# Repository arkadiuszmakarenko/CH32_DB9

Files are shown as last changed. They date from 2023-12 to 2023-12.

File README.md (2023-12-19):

Work in progress.

USB HID to DB9 Adapter
It has been desigend for dual use, but primarily for MSX computers.

Current support:
- MSX Gamepad

2023-12-19 16_24_46-JLCPCB PCBA Viewer

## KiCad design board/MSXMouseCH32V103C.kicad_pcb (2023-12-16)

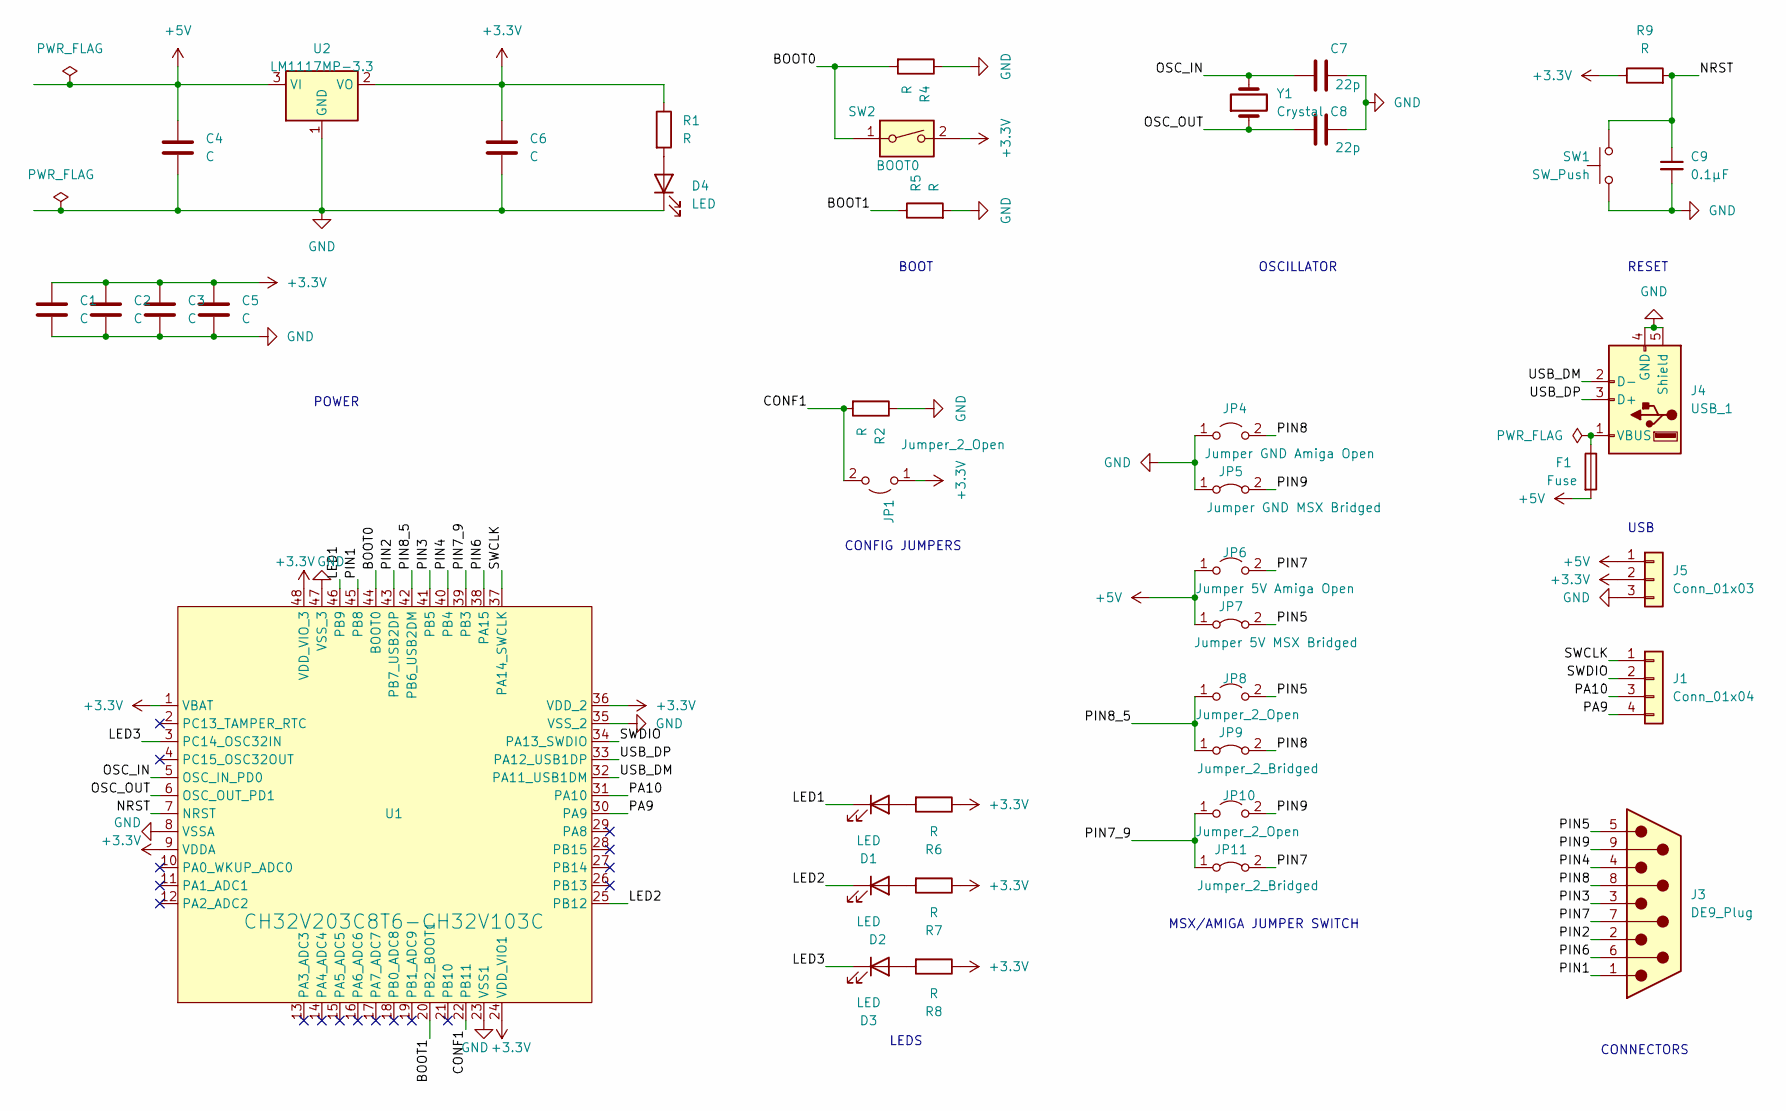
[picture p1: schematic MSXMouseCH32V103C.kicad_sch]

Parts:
C1, C2, C3, C4, C5, C6: C; C_0805_2012Metric_Pad1.18x1.45mm_HandSolder
C7, C8: 22p; C_0805_2012Metric_Pad1.18x1.45mm_HandSolder
C9: 0.1μF; C_0603_1608Metric; LCSC C14663
D1, D2, D3, D4: LED; LED_0805_2012Metric_Pad1.15x1.40mm_HandSolder
F1: Fuse; Fuse_1206_3216Metric_Pad1.42x1.75mm_HandSolder
J1: Conn_01x04; PinHeader_1x04_P2.54mm_Vertical
J3: DE9_Plug; DSUB-9_Female_EdgeMount_P2.77mm
J4: USB_1; USB_A_CONNFLY_DS1095-WNR0
J5: Conn_01x03; PinHeader_1x03_P2.54mm_Vertical
JP1, JP8, JP10: Jumper_2_Open; SolderJumper-2_P1.3mm_Open_RoundedPad1.0x1.5mm
JP4: Jumper GND Amiga Open; SolderJumper-2_P1.3mm_Open_RoundedPad1.0x1.5mm
JP5: Jumper GND MSX Bridged; SolderJumper-2_P1.3mm_Bridged_RoundedPad1.0x1.5mm
JP6: Jumper 5V Amiga Open; SolderJumper-2_P1.3mm_Open_RoundedPad1.0x1.5mm
JP7: Jumper 5V MSX Bridged; SolderJumper-2_P1.3mm_Bridged_RoundedPad1.0x1.5mm
JP9, JP11: Jumper_2_Bridged; SolderJumper-2_P1.3mm_Bridged_RoundedPad1.0x1.5mm
R1, R2, R4, R5, R6, R7, R8, R9: R; R_0805_2012Metric_Pad1.20x1.40mm_HandSolder
SW1: SW_Push; PinSocket_1x02_P2.54mm_Vertical; LCSC C2888884
SW2: BOOT0; PinHeader_1x02_P2.54mm_Vertical
U1: CH32V203C8T6-CH32V103C; CH32V203C8T6_LQFP-48_7x7mm_P0.5mm
U2: LM1117MP-3.3; SOT-223-3_TabPin2
Y1: Crystal; Crystal_HC49-U_Vertical

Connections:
+3.3V: C1.1, C2.1, C3.1, C5.1, C6.1, J5.2, JP1.1 (A), R1.1, R6.1, R7.1, R8.1, R9.1, SW2.2, U1.1 (VBAT), U1.9 (VDDA), U1.24 (VDD_VIO1), U1.36 (VDD_2), U1.48 (VDD_VIO_3), U2.2 (VO)
+5V: C4.1, F1.2, J5.1, JP6.1 (A), JP7.1 (A), U2.3 (VI)
/BOOT0: R4.2, SW2.1, U1.44 (BOOT0)
/BOOT1: R5.1, U1.20 (PB2_BOOT1)
/CONF1: JP1.2 (B), R2.2, U1.22 (PB11)
/LED1: D1.1 (K), U1.46 (PB9)
/LED2: D2.1 (K), U1.25 (PB12)
/LED3: D3.1 (K), U1.3 (PC14_OSC32IN)
/NRST: C9.1, R9.2, SW1.2, U1.7 (NRST)
/OSC_IN: C7.1, U1.5 (OSC_IN_PD0), Y1.2
/OSC_OUT: C8.1, U1.6 (OSC_OUT_PD1), Y1.1
/PA9: J1.4, U1.30 (PA9)
/PA10: J1.3, U1.31 (PA10)
/PIN1: J3.1, U1.45 (PB8)
/PIN2: J3.2, U1.43 (PB7_USB2DP)
/PIN3: J3.3, U1.41 (PB5)
/PIN4: J3.4, U1.40 (PB4)
/PIN5: J3.5, JP7.2 (B), JP8.2 (B)
/PIN6: J3.6, U1.38 (PA15)
/PIN7: J3.7, JP6.2 (B), JP11.2 (B)
/PIN7_9: JP10.1 (A), JP11.1 (A), U1.39 (PB3)
/PIN8: J3.8, JP4.2 (B), JP9.2 (B)
/PIN8_5: JP8.1 (A), JP9.1 (A), U1.42 (PB6_USB2DM)
/PIN9: J3.9, JP5.2 (B), JP10.2 (B)
/SWCLK: J1.1, U1.37 (PA14_SWCLK)
/SWDIO: J1.2, U1.34 (PA13_SWDIO)
/USB_DM: J4.2 (D-), U1.32 (PA11_USB1DM)
/USB_DP: J4.3 (D+), U1.33 (PA12_USB1DP)
GND: C1.2, C2.2, C3.2, C4.2, C5.2, C6.2, C7.2, C8.2, C9.2, D4.1 (K), J4.4 (GND), J4.5 (Shield), J5.3, JP4.1 (A), JP5.1 (A), R2.1, R4.1, R5.2, SW1.1, U1.8 (VSSA), U1.23 (VSS1), U1.35 (VSS_2), U1.47 (VSS_3), U2.1 (GND)
unnamed: D1.2 (A), R6.2
unnamed: D2.2 (A), R7.2
unnamed: D3.2 (A), R8.2
unnamed: D4.2 (A), R1.2
unnamed: F1.1, J4.1 (VBUS)

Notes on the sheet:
CONNECTORS
CONFIG JUMPERS
OSCILLATOR
LEDS
MSX/AMIGA JUMPER SWITCH
USB
BOOT
POWER
RESET

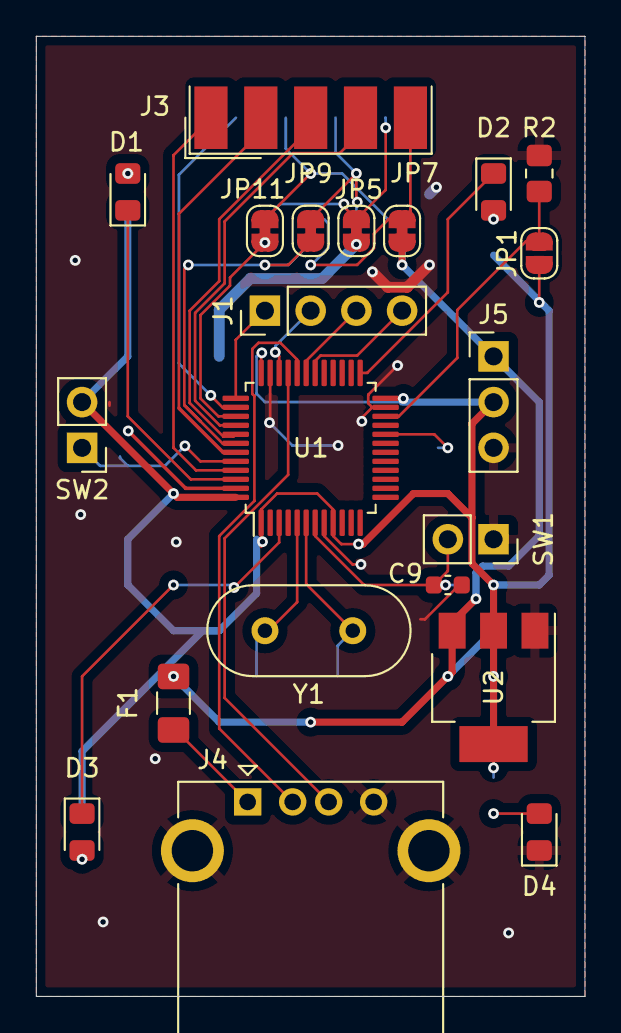
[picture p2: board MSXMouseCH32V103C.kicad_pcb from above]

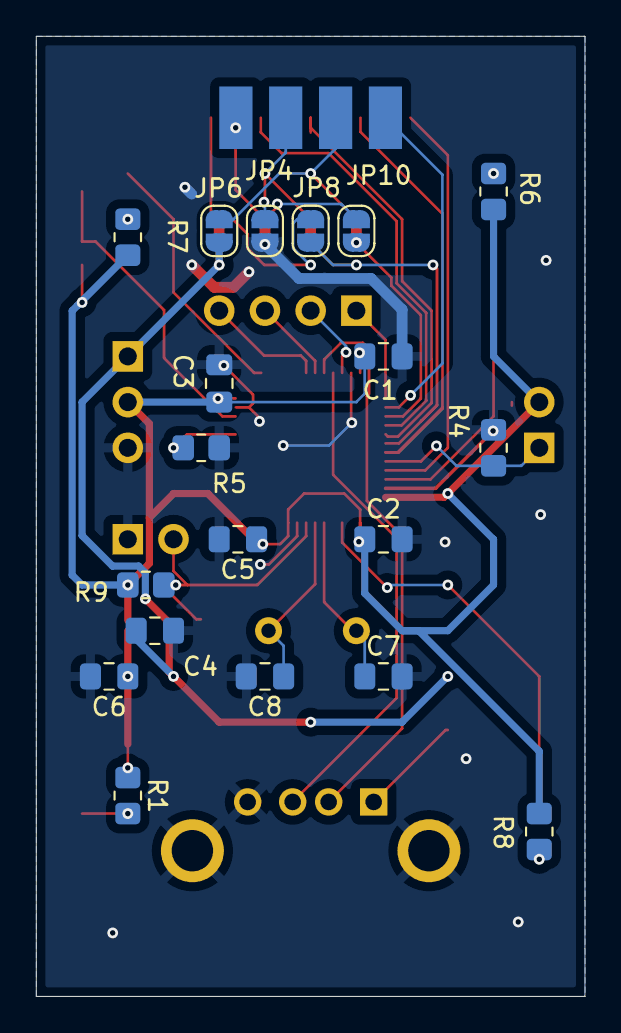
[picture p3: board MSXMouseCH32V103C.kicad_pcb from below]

Board: 2 copper layers, 30.5 x 53.3 mm, 40 parts (19 on the bottom side), 34 nets.

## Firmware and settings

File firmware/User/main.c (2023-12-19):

/********************************** (C) COPYRIGHT *******************************
 * File Name          : main.c
 * Author             : WCH
 * Version            : V1.0.0
 * Date               : 2020/04/30
 * Description        : Main program body.
 *********************************************************************************
 * Copyright (c) 2021 Nanjing Qinheng Microelectronics Co., Ltd.
 * Attention: This software (modified or not) and binary are used for 
 * microcontroller manufactured by Nanjing Qinheng Microelectronics.
 *******************************************************************************/

/*
 *@Note
 *USART Print debugging routine:
 *USART1_Tx(PA9).
 *This example demonstrates using USART1(PA9) as a print debug port output.
 *
 */

#include "debug.h"

/*******************************************************************************/
/* Header File */
#include <USB_Host/usb_gamepad.h>
#include <USB_Host/usb_mouse.h>
#include <USB_Host/usb_keyboard.h>
#include "USB_Host/usb_host_config.h"
#include "utils.h"
#include "tim.h"
#include "mouseAmiga.h"
#include "mouseMSX.h"
#include "gpio.h"
#include "gamepadAmiga.h"
#include "gamepadMSX.h"

/*********************************************************************
 * @fn      main
 *
 * @brief   Main program.
 *
 * @return  none
 */



int main(void)
{
    uint8_t CONFIG1 = 0;

    NVIC_PriorityGroupConfig(NVIC_PriorityGroup_2);
    SystemCoreClockUpdate();
    Delay_Init();
    USART_Printf_Init(115200);
    DUG_PRINTF( "ChipID:%08x\r\n", DBGMCU_GetCHIPID() );
    DUG_PRINTF( "SystemClk:%d\r\n", SystemCoreClock );
    DUG_PRINTF( "USBHD HOST KM Test\r\n" );

    /* Initialize timer for obtaining keyboard and mouse data at regular intervals */
    TIM3_Init( 9, SystemCoreClock / 10000 - 1 );
    DUG_PRINTF( "TIM3 Init OK!\r\n" );

    /* Configure USB clock and initialize USB host */
#if DEF_USBHD_PORT_EN
    USBHD_RCC_Init( );
    USBHD_Host_Init( ENABLE , PWR_VDD_SupplyVoltage());
    memset( &RootHubDev.bStatus, 0, sizeof( ROOT_HUB_DEVICE ) );
    memset( &HostCtl[ DEF_USBHD_PORT_INDEX * DEF_ONE_USB_SUP_DEV_TOTAL ].InterfaceNum, 0, DEF_ONE_USB_SUP_DEV_TOTAL * sizeof( HOST_CTL ) );
#endif
	GPIO_Config();
	 //Read value of CONFIG1
	CONFIG1 = GPIO_ReadInputDataBit(CONFIG1_GPIO_Port, CONFIG1_Pin);


	DUG_PRINTF( "CONFIG1:%d\r\n", CONFIG1);

	while (1) {
		USBH_MainDeal();

		//Handle HID Device
		if (RootHubDev.bType == USB_DEV_CLASS_HID) {

			for (int itf = 0; itf < DEF_INTERFACE_NUM_MAX; itf++) {
				//Handle mouse
				if (HostCtl[0].Interface[itf].HIDRptDesc.type
						== REPORT_TYPE_MOUSE) {
					HID_MOUSE_Info_TypeDef *mousemap = USBH_GetMouseInfo(
							&HostCtl[0].Interface[itf]);
	                 if(CONFIG1)
	                 {
	                    ProcessMouse(mousemap);
	                 }else
	                 {
	                    ProcessMouseMSX(mousemap);
	                 }
				}

				//Handle gamepad
				if (HostCtl[0].Interface[itf].HIDRptDesc.type
						== REPORT_TYPE_JOYSTICK) {

		HID_gamepad_Info_TypeDef *gamepad = GetGamepadInfo(
							&HostCtl[0].Interface[itf]);

		                    if(CONFIG1)
                            {
                                ProcessGamepadAmiga(gamepad);
                            } else
                            {
                                ProcessGamepadMSX(gamepad);
                            }
				}
			}
		}

		//Handle HUB Device

		if (RootHubDev.bType == USB_DEV_CLASS_HUB) {

			//Iterate over all devices
			for (uint8_t device = 1; device < 5; device++)
			{
				//Iterate over all interfaces
				for (int itf = 0; itf < DEF_INTERFACE_NUM_MAX; itf++) {
					//Handle mouse
					if (HostCtl[device].Interface[itf].HIDRptDesc.type
							== REPORT_TYPE_MOUSE) {
						HID_MOUSE_Info_TypeDef *mousemap = USBH_GetMouseInfo(
								&HostCtl[device].Interface[itf]);


                        if(CONFIG1)
                        {
							ProcessMouse(mousemap);
                        }else
                         {
							ProcessMouseMSX(mousemap);
                         }

					}

					//Handle gamepad
					if (HostCtl[device].Interface[itf].HIDRptDesc.type
							== REPORT_TYPE_JOYSTICK) {

			HID_gamepad_Info_TypeDef *gamepad = GetGamepadInfo(
								&HostCtl[device].Interface[itf]);

			                if(CONFIG1)
			                {
			                    ProcessGamepadAmiga(gamepad);
			                } else
			                {
			                    ProcessGamepadMSX(gamepad);
			                }

					    }
				    }
				}
			}
		}
	}

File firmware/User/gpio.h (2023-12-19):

#ifndef __GPIO_H
#define __GPIO_H

#include "ch32v10x_gpio.h"

//CONFIG
#define CONFIG1_Pin GPIO_Pin_11
#define CONFIG1_GPIO_Port GPIOB


//LEDs
#define LED1_Pin GPIO_Pin_9
#define LED1_GPIO_Port GPIOB

#define LED2_Pin GPIO_Pin_12
#define LED2_GPIO_Port GPIOB

#define LED3_Pin GPIO_Pin_14
#define LED3_GPIO_Port GPIOC



//BUTTONS
#define RB_Pin GPIO_Pin_3
#define RB_GPIO_Port GPIOB

#define MB_Pin GPIO_Pin_6
#define MB_GPIO_Port GPIOB

#define LB_Pin GPIO_Pin_15
#define LB_GPIO_Port GPIOA

//DIRECTIONS
#define RHQ_Pin GPIO_Pin_4
#define RHQ_GPIO_Port GPIOB

#define LVQ_Pin GPIO_Pin_5
#define LVQ_GPIO_Port GPIOB

#define BH_Pin GPIO_Pin_7
#define BH_GPIO_Port GPIOB

#define FV_Pin GPIO_Pin_8
#define FV_GPIO_Port GPIOB

//DB9 PIN

#define PIN1_Pin GPIO_Pin_8
#define PIN1_GPIO_Port GPIOB

#define PIN2_Pin GPIO_Pin_7
#define PIN2_GPIO_Port GPIOB

#define PIN3_Pin GPIO_Pin_5
#define PIN3_GPIO_Port GPIOB

#define PIN4_Pin GPIO_Pin_4
#define PIN4_GPIO_Port GPIOB

#define PIN85_Pin GPIO_Pin_6
#define PIN85_GPIO_Port GPIOB

#define PIN79_Pin GPIO_Pin_3
#define PIN79_GPIO_Port GPIOB

#define PIN6_Pin GPIO_Pin_15
#define PIN6_GPIO_Port GPIOA










void GPIO_Config();


#endif

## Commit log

2023-12-16 Project Rename
    [MSXMouseCH32V103C.kicad_pcb, MSXMouseCH32V103C.kicad_sch, MSXMouseCH32V203.kicad_pcb]
2023-12-16 Project restructure
    [MSXMouseCH32V103C.kicad_pcb, MSXMouseCH32V103C.kicad_sch]
